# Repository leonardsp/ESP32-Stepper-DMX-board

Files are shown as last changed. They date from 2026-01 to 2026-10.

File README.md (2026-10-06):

# ESP32-Stepper-DMX-board

## DMX Channels

The current firmware implements the real motor + LED-dimmer DMX profile. There is no WLED DMX implementation in this build.

Combined fixture profile (LED dimmer default start address = 8):

1   - LED Pan
2   - LED Pan fine
3   - Ref Pan
4   - Ref Pan fine
5   - LED Pan Inv (0 stop / 1-127 CCW / 128 stop / 129-255 CW)
6   - Ref Pan Inv (0 stop / 1-127 CCW / 128 stop / 129-255 CW)
7   - Reset / Homing (0 no / 1-255 start)
8   - Dimmer 0 coarse
9   - Dimmer 0 fine
10  - Dimmer 1 coarse
11  - Dimmer 1 fine
12  - Dimmer 2 coarse
13  - Dimmer 2 fine
14  - Dimmer 3 coarse
15  - Dimmer 3 fine
16  - Dimmer 4 coarse
17  - Dimmer 4 fine
18  - Dimmer 5 coarse
19  - Dimmer 5 fine
20  - Dimmer 6 coarse
21  - Dimmer 6 fine
22  - Dimmer 7 coarse
23  - Dimmer 7 fine
24  - Strobe (0 off / 1-255 speed)
25-240 - RGB pixel data for 72 LEDs (3 channels per LED)

## Connector Pinout
1 - GND
2 - +24V
3 - DMX_B (xlr pin 2)
4 - DMX_A (xlr pin 3)

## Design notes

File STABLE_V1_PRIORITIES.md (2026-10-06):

# Stable V1 Priorities (ESP32-Stepper-DMX-board)

Stand: 2026-08-28
Ziel: eine technisch stabile, betriebssichere erste Version fuer Show-Einsatz.

## 1) P0 Kritisch (MUSS vor Stable V1)

### P0-3: WS2813/Pixel-Stabilitaet nach DMX-Verlust (nur erste ~10 LEDs / random)
- Symptom: nach DMX-Loss oder sporadisch arbeiten nur erste Pixel korrekt.
- Risiko: sichtbarer Show-Fehler.
- Wahrscheinliche technische Ursachen:
  - Keine harte Paketlaengen-Validierung vor Kanalzugriffen.
  - Treiber ist auf WS2812B konfiguriert, Hardwaremeldung nennt WS2813.
- Entscheidung fuer V1:
  - DMX Paketgroesse strikt validieren (nur verarbeiten, wenn voller Footprint vorhanden).
  - Bei unvollstaendigen Frames: fail-safe (letzter gueltiger Zustand oder definierter Blackout).
  - LED Typ/Timing passend zur realen Hardware fixieren und validieren.

### P0-4: Position + kontinuierliche Rotation verliert Referenz/systematischer Fehler
- Symptom: Positionsdrift/Lost Position bei gleichzeitiger Pan-Position und Rotation.
- Risiko: mechanische Fehlposition im Betrieb.
- Hinweis: wirkt algorithmisch/systematisch, nicht nur Step-Loss.
- Entscheidung fuer V1:
  - Bewegungsmodell vereinheitlichen: klarer Zustandsautomat fuer Position, Hold, Rotation.
  - Offset- und Uebergangslogik (0/128/rotating) deterministisch machen.
  - Reproduzierbarer Testfall als Release-Gate (mehrere Minuten kontinuierlich).

### P0-2: DMX Timeout Anforderung stimmt nicht mit Implementierung
- Anforderung: DMX Timeout = 60s.
- Ist-Code: Timeout steht auf 5s.
- Risiko: unnoetige Motor-Disable/Homing-Zyklen bei kurzen DMX-Aussetzern.
- Entscheidung fuer V1:
  - Timeout auf exakt 60s setzen.
  - Bei Timeout: Stepper disable.
  - Bei DMX Rueckkehr: zwingend Rehoming vor normalem Betrieb.
  - Timeout/Homing Verhalten mit realen DMX-Ausfaellen testen und protokollieren.

### P0-1: COB Fan schaltet nicht sicher bei hoher Last
- Symptom: Luefter startet nicht zuverlaessig, auch wenn COB-Last hoch ist.
- Risiko: thermische Ueberlastung, Leistungsabfall, Hardware-Schaden.
- Beobachtung aus Code:
  - Fan wird ueber einen Integrator mit langer Rise-Time geregelt.
  - Aktivierung erst ueber FAN_ENABLE_THRESHOLD.
- Entscheidung fuer V1:
  - Fan-Sicherheitsmodus einfuehren: bei hoher Last (z. B. >=80% Dimmer oder Pixel-Last >=70%) sofort Fan ON.
  - Thermal-Schutz als harte Prioritaet behandeln (nie ohne aktive Kuehlung bei hoher Last).
  - Kurzer Hardwaretest unter Dauerlast (mind. 20-30 min) als Release-Gate.

### P0-5: Feste DMX-Adressen fuer alle 8 ESP-Controller
- Symptom: uneinheitliche oder nicht final festgelegte DMX-Adressierung im Gesamtsystem.
- Risiko: Patching-Fehler, unvorhersehbares Verhalten im Show-Betrieb, hoher Setup-Aufwand.
- Entscheidung fuer V1:
  - Feste, dokumentierte Startadressen pro Controller definieren.
  - Adressplan in Doku + Konfiguration synchron halten.
  - Endtest mit kompletter 8-ESP-Konstellation als Release-Gate.

## 2) P1 Hoch (sollte in V1 wenn Zeit reicht)

### P1-1: RDM Zuverlaessigkeit im Vollbetrieb
- Symptom: bekannte RDM Probleme.
- Risiko: schlechte Erkennbarkeit/Steuerbarkeit an Lichtpulten.
- Beobachtung:
  - Es gibt separate rdm_test Firmware -> Hinweis auf noch nicht robuste Integration im Hauptbuild.
- Entscheidung fuer V1:
  - RDM Grundfunktionen als Mindestumfang absichern: Discovery, DMX Start Address, Personality, Device Label.
  - Lasttests mit aktivem Pixel/Dimmer-Rendering + RDM Polling.
  - Falls nicht voll stabil: RDM Scope fuer V1 klar begrenzen und dokumentieren.

### P1-2: Fehlerpfad bei Homing-Fehlern
- Symptom: Fehler werden zwar geloggt, aber kaum Recovery/Benutzerfeedback.
- Risiko: unklarer Betriebszustand nach fehlgeschlagenem Homing.
- Entscheidung fuer V1:
  - Klaren Safe-State definieren (Ausgaenge aus, Bewegung stop, Fehlerflag).
  - Sichtbares Fehlerfeedback (z. B. Diagnose-LED oder serieller Fehlercode) definieren.

## 3) P2 Mittel (nach Stable V1 verschiebbar)

### P2-1: Placeholder/TODOs ohne direkten Show-Blocker
- RDM Identify Callback ist nur Platzhalter.
- Geplante Weiterleitung DMX -> Serial2 ist TODO.

### P2-2: Hardware/Validierungsaufgaben aus TODO.md
- Mechanik-/Elektroniktests sind nur teilweise dokumentiert.
- Fuer V1 reicht fokussierter Abnahmetest, umfassende Validierung kann in V1.1 folgen.

## 4) Konkrete Stable-V1 Zieldefinition (MUSS)

1. Pixel-Robustheit: kein "nur erste LEDs" Fehler nach DMX-Loss/Reconnect.
2. Bewegungsstabilitaet: keine systematische Positionsdrift bei Position+Rotation.
3. DMX Fail-Safe: 60s Timeout, dann Stepper disable; bei Rueckkehr obligatorisches Rehoming.
4. Thermische Sicherheit: Fan startet sicher unter hoher Last und verhindert Ueberhitzung.
5. Feste DMX-Adressen fuer die insgesamt 8 verschiedenen ESPs.

## 5) Release Gates (Go/No-Go Tests)

1. 10x DMX Reconnect-Test ohne Pixel-Ausfall/Random-Muster.
2. 20 min Bewegungstest mit gemischter Position/Rotation ohne Referenzverlust.
3. 10x DMX Ausfall/Rueckkehr-Zyklus mit 60s Timeout, jedes Mal korrektes Disable/Rehome.
4. 30 min Vollast-Test (Dimmer + Pixel) ohne thermischen Fehler.
5. RDM Discovery und Parameter-Aenderung von mindestens 2 unterschiedlichen Lichtpult/Tools.

## 6) Empfohlene Reihenfolge (wenn wenig Zeit)

1. Pixel/WS2813 Stabilitaet nach DMX-Loss (P0-3)
2. Rotation+Position Drift fixen (P0-4)
3. DMX Timeout auf 60s + Rehome-Flow absichern (P0-2)
4. Fan/Thermal Fix + Test (P0-1)
5. Feste DMX-Adressen fuer 8 ESPs finalisieren (P0-5)
6. RDM Mindeststabilitaet verifizieren (P1-1)

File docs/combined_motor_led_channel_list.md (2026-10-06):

# Combined DMX Channel List (Motor + LED Dimmer)

This list assumes both controllers run together with LED dimmer default start address at **8**.

| Channel | Name | Controller |
|---:|---|---|
| 1 | LED Pan | motor_dmx |
| 2 | LED Pan fine | motor_dmx |
| 3 | Ref Pan | motor_dmx |
| 4 | Ref Pan fine | motor_dmx |
| 5 | LED Pan Inv (0 stop / 1-127 CCW / 128 stop / 129-255 CW) | motor_dmx |
| 6 | Ref Pan Inv (0 stop / 1-127 CCW / 128 stop / 129-255 CW) | motor_dmx |
| 7 | Reset / Homing (0 no, 1-255 start) | motor_dmx |
| 8 | Dimmer 0 coarse | led_dimmer |
| 9 | Dimmer 0 fine | led_dimmer |
| 10 | Dimmer 1 coarse | led_dimmer |
| 11 | Dimmer 1 fine | led_dimmer |
| 12 | Dimmer 2 coarse | led_dimmer |
| 13 | Dimmer 2 fine | led_dimmer |
| 14 | Dimmer 3 coarse | led_dimmer |
| 15 | Dimmer 3 fine | led_dimmer |
| 16 | Dimmer 4 coarse | led_dimmer |
| 17 | Dimmer 4 fine | led_dimmer |
| 18 | Dimmer 5 coarse | led_dimmer |
| 19 | Dimmer 5 fine | led_dimmer |
| 20 | Dimmer 6 coarse | led_dimmer |
| 21 | Dimmer 6 fine | led_dimmer |
| 22 | Dimmer 7 coarse | led_dimmer |
| 23 | Dimmer 7 fine | led_dimmer |
| 24 | Strobe (0 off, 1-255 speed) | led_dimmer |
| 25 | Pixel 1 Red | led_dimmer |
| 26 | Pixel 1 Green | led_dimmer |
| 27 | Pixel 1 Blue | led_dimmer |
| 28 | Pixel 2 Red | led_dimmer |
| 29 | Pixel 2 Green | led_dimmer |
| 30 | Pixel 2 Blue | led_dimmer |
| 31 | Pixel 3 Red | led_dimmer |
| 32 | Pixel 3 Green | led_dimmer |
| 33 | Pixel 3 Blue | led_dimmer |
| 34 | Pixel 4 Red | led_dimmer |
| 35 | Pixel 4 Green | led_dimmer |
| 36 | Pixel 4 Blue | led_dimmer |
| 37 | Pixel 5 Red | led_dimmer |
| 38 | Pixel 5 Green | led_dimmer |
| 39 | Pixel 5 Blue | led_dimmer |
| 40 | Pixel 6 Red | led_dimmer |
| 41 | Pixel 6 Green | led_dimmer |
| 42 | Pixel 6 Blue | led_dimmer |
| 43 | Pixel 7 Red | led_dimmer |
| 44 | Pixel 7 Green | led_dimmer |
| 45 | Pixel 7 Blue | led_dimmer |
| 46 | Pixel 8 Red | led_dimmer |
| 47 | Pixel 8 Green | led_dimmer |
| 48 | Pixel 8 Blue | led_dimmer |
| 49 | Pixel 9 Red | led_dimmer |
| 50 | Pixel 9 Green | led_dimmer |
| 51 | Pixel 9 Blue | led_dimmer |
| 52 | Pixel 10 Red | led_dimmer |
| 53 | Pixel 10 Green | led_dimmer |
| 54 | Pixel 10 Blue | led_dimmer |
| 55 | Pixel 11 Red | led_dimmer |
| 56 | Pixel 11 Green | led_dimmer |
| 57 | Pixel 11 Blue | led_dimmer |
| 58 | Pixel 12 Red | led_dimmer |
| 59 | Pixel 12 Green | led_dimmer |
| 60 | Pixel 12 Blue | led_dimmer |
| 61 | Pixel 13 Red | led_dimmer |
| 62 | Pixel 13 Green | led_dimmer |
| 63 | Pixel 13 Blue | led_dimmer |
| 64 | Pixel 14 Red | led_dimmer |
| 65 | Pixel 14 Green | led_dimmer |
| 66 | Pixel 14 Blue | led_dimmer |
| 67 | Pixel 15 Red | led_dimmer |
| 68 | Pixel 15 Green | led_dimmer |
| 69 | Pixel 15 Blue | led_dimmer |
| 70 | Pixel 16 Red | led_dimmer |
| 71 | Pixel 16 Green | led_dimmer |
| 72 | Pixel 16 Blue | led_dimmer |
| 73 | Pixel 17 Red | led_dimmer |
| 74 | Pixel 17 Green | led_dimmer |
| 75 | Pixel 17 Blue | led_dimmer |
| 76 | Pixel 18 Red | led_dimmer |
| 77 | Pixel 18 Green | led_dimmer |
| 78 | Pixel 18 Blue | led_dimmer |
| 79 | Pixel 19 Red | led_dimmer |
| 80 | Pixel 19 Green | led_dimmer |
| 81 | Pixel 19 Blue | led_dimmer |
| 82 | Pixel 20 Red | led_dimmer |
| 83 | Pixel 20 Green | led_dimmer |
| 84 | Pixel 20 Blue | led_dimmer |
| 85 | Pixel 21 Red | led_dimmer |
| 86 | Pixel 21 Green | led_dimmer |
| 87 | Pixel 21 Blue | led_dimmer |
| 88 | Pixel 22 Red | led_dimmer |
| 89 | Pixel 22 Green | led_dimmer |
| 90 | Pixel 22 Blue | led_dimmer |
| 91 | Pixel 23 Red | led_dimmer |
| 92 | Pixel 23 Green | led_dimmer |
| 93 | Pixel 23 Blue | led_dimmer |
| 94 | Pixel 24 Red | led_dimmer |
| 95 | Pixel 24 Green | led_dimmer |
| 96 | Pixel 24 Blue | led_dimmer |
| 97 | Pixel 25 Red | led_dimmer |
| 98 | Pixel 25 Green | led_dimmer |
| 99 | Pixel 25 Blue | led_dimmer |
| 100 | Pixel 26 Red | led_dimmer |
| 101 | Pixel 26 Green | led_dimmer |
| 102 | Pixel 26 Blue | led_dimmer |
| 103 | Pixel 27 Red | led_dimmer |
| 104 | Pixel 27 Green | led_dimmer |
| 105 | Pixel 27 Blue | led_dimmer |
| 106 | Pixel 28 Red | led_dimmer |
| 107 | Pixel 28 Green | led_dimmer |
| 108 | Pixel 28 Blue | led_dimmer |
| 109 | Pixel 29 Red | led_dimmer |
| 110 | Pixel 29 Green | led_dimmer |
| 111 | Pixel 29 Blue | led_dimmer |
| 112 | Pixel 30 Red | led_dimmer |
| 113 | Pixel 30 Green | led_dimmer |
| 114 | Pixel 30 Blue | led_dimmer |
| 115 | Pixel 31 Red | led_dimmer |
| 116 | Pixel 31 Green | led_dimmer |
| 117 | Pixel 31 Blue | led_dimmer |
| 118 | Pixel 32 Red | led_dimmer |
| 119 | Pixel 32 Green | led_dimmer |
| 120 | Pixel 32 Blue | led_dimmer |
| 121 | Pixel 33 Red | led_dimmer |
| 122 | Pixel 33 Green | led_dimmer |
| 123 | Pixel 33 Blue | led_dimmer |
| 124 | Pixel 34 Red | led_dimmer |
| 125 | Pixel 34 Green | led_dimmer |
| 126 | Pixel 34 Blue | led_dimmer |
| 127 | Pixel 35 Red | led_dimmer |
| 128 | Pixel 35 Green | led_dimmer |
| 129 | Pixel 35 Blue | led_dimmer |
| 130 | Pixel 36 Red | led_dimmer |
| 131 | Pixel 36 Green | led_dimmer |
| 132 | Pixel 36 Blue | led_dimmer |
| 133 | Pixel 37 Red | led_dimmer |
| 134 | Pixel 37 Green | led_dimmer |
| 135 | Pixel 37 Blue | led_dimmer |
| 136 | Pixel 38 Red | led_dimmer |
| 137 | Pixel 38 Green | led_dimmer |
| 138 | Pixel 38 Blue | led_dimmer |
| 139 | Pixel 39 Red | led_dimmer |
| 140 | Pixel 39 Green | led_dimmer |
| 141 | Pixel 39 Blue | led_dimmer |
| 142 | Pixel 40 Red | led_dimmer |
| 143 | Pixel 40 Green | led_dimmer |
| 144 | Pixel 40 Blue | led_dimmer |
| 145 | Pixel 41 Red | led_dimmer |
| 146 | Pixel 41 Green | led_dimmer |
| 147 | Pixel 41 Blue | led_dimmer |
| 148 | Pixel 42 Red | led_dimmer |
| 149 | Pixel 42 Green | led_dimmer |
| 150 | Pixel 42 Blue | led_dimmer |
| 151 | Pixel 43 Red | led_dimmer |
| 152 | Pixel 43 Green | led_dimmer |
| 153 | Pixel 43 Blue | led_dimmer |
| 154 | Pixel 44 Red | led_dimmer |
| 155 | Pixel 44 Green | led_dimmer |
| 156 | Pixel 44 Blue | led_dimmer |
| 157 | Pixel 45 Red | led_dimmer |
| 158 | Pixel 45 Green | led_dimmer |
| 159 | Pixel 45 Blue | led_dimmer |
| 160 | Pixel 46 Red | led_dimmer |
| 161 | Pixel 46 Green | led_dimmer |
| 162 | Pixel 46 Blue | led_dimmer |
| 163 | Pixel 47 Red | led_dimmer |
| 164 | Pixel 47 Green | led_dimmer |
| 165 | Pixel 47 Blue | led_dimmer |
| 166 | Pixel 48 Red | led_dimmer |
| 167 | Pixel 48 Green | led_dimmer |
| 168 | Pixel 48 Blue | led_dimmer |
| 169 | Pixel 49 Red | led_dimmer |
| 170 | Pixel 49 Green | led_dimmer |
| 171 | Pixel 49 Blue | led_dimmer |
| 172 | Pixel 50 Red | led_dimmer |
| 173 | Pixel 50 Green | led_dimmer |
| 174 | Pixel 50 Blue | led_dimmer |
| 175 | Pixel 51 Red | led_dimmer |
| 176 | Pixel 51 Green | led_dimmer |
| 177 | Pixel 51 Blue | led_dimmer |
| 178 | Pixel 52 Red | led_dimmer |
| 179 | Pixel 52 Green | led_dimmer |
| 180 | Pixel 52 Blue | led_dimmer |
| 181 | Pixel 53 Red | led_dimmer |
| 182 | Pixel 53 Green | led_dimmer |
| 183 | Pixel 53 Blue | led_dimmer |
| 184 | Pixel 54 Red | led_dimmer |
| 185 | Pixel 54 Green | led_dimmer |
| 186 | Pixel 54 Blue | led_dimmer |
| 187 | Pixel 55 Red | led_dimmer |
| 188 | Pixel 55 Green | led_dimmer |
| 189 | Pixel 55 Blue | led_dimmer |
| 190 | Pixel 56 Red | led_dimmer |
| 191 | Pixel 56 Green | led_dimmer |
| 192 | Pixel 56 Blue | led_dimmer |
| 193 | Pixel 57 Red | led_dimmer |
| 194 | Pixel 57 Green | led_dimmer |
| 195 | Pixel 57 Blue | led_dimmer |
| 196 | Pixel 58 Red | led_dimmer |
| 197 | Pixel 58 Green | led_dimmer |
| 198 | Pixel 58 Blue | led_dimmer |
| 199 | Pixel 59 Red | led_dimmer |
| 200 | Pixel 59 Green | led_dimmer |
| 201 | Pixel 59 Blue | led_dimmer |
| 202 | Pixel 60 Red | led_dimmer |
| 203 | Pixel 60 Green | led_dimmer |
| 204 | Pixel 60 Blue | led_dimmer |
| 205 | Pixel 61 Red | led_dimmer |
| 206 | Pixel 61 Green | led_dimmer |
| 207 | Pixel 61 Blue | led_dimmer |
| 208 | Pixel 62 Red | led_dimmer |
| 209 | Pixel 62 Green | led_dimmer |
| 210 | Pixel 62 Blue | led_dimmer |
| 211 | Pixel 63 Red | led_dimmer |
| 212 | Pixel 63 Green | led_dimmer |
| 213 | Pixel 63 Blue | led_dimmer |
| 214 | Pixel 64 Red | led_dimmer |
| 215 | Pixel 64 Green | led_dimmer |
| 216 | Pixel 64 Blue | led_dimmer |
| 217 | Pixel 65 Red | led_dimmer |
| 218 | Pixel 65 Green | led_dimmer |
| 219 | Pixel 65 Blue | led_dimmer |
| 220 | Pixel 66 Red | led_dimmer |
| 221 | Pixel 66 Green | led_dimmer |
| 222 | Pixel 66 Blue | led_dimmer |
| 223 | Pixel 67 Red | led_dimmer |
| 224 | Pixel 67 Green | led_dimmer |
| 225 | Pixel 67 Blue | led_dimmer |
| 226 | Pixel 68 Red | led_dimmer |
| 227 | Pixel 68 Green | led_dimmer |
| 228 | Pixel 68 Blue | led_dimmer |
| 229 | Pixel 69 Red | led_dimmer |
| 230 | Pixel 69 Green | led_dimmer |
| 231 | Pixel 69 Blue | led_dimmer |
| 232 | Pixel 70 Red | led_dimmer |
| 233 | Pixel 70 Green | led_dimmer |
| 234 | Pixel 70 Blue | led_dimmer |
| 235 | Pixel 71 Red | led_dimmer |
| 236 | Pixel 71 Green | led_dimmer |
| 237 | Pixel 71 Blue | led_dimmer |
| 238 | Pixel 72 Red | led_dimmer |
| 239 | Pixel 72 Green | led_dimmer |
| 240 | Pixel 72 Blue | led_dimmer |

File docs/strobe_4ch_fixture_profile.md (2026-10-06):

# Strobe 4CH Fixture Profile

This file documents the DMX personalities and macro channel mapping for the `strobe_4ch` firmware.

## Personalities

### 1) Simple (2ch)
- CH1: Master dimmer (8-bit)
- CH2: Strobe (0=open, 1..255=slow..fast)

### 2) Simple Fine (3ch)
- CH1: Master dimmer coarse
- CH2: Master dimmer fine
- CH3: Strobe

### 3) Simple Macro (3ch)
- CH1: Master dimmer (8-bit)
- CH2: Strobe
- CH3: Macro

### 4) Compatibility (5ch)
- CH1: Dimmer 1 (8-bit)
- CH2: Dimmer 2 (8-bit)
- CH3: Dimmer 3 (8-bit)
- CH4: Dimmer 4 (8-bit)
- CH5: Strobe

### 5) Compatibility Macro (6ch)
- CH1: Dimmer 1 (8-bit)
- CH2: Dimmer 2 (8-bit)
- CH3: Dimmer 3 (8-bit)
- CH4: Dimmer 4 (8-bit)
- CH5: Strobe
- CH6: Macro

### 6) Advanced (10ch)
- CH1: Dimmer 1 coarse
- CH2: Dimmer 1 fine
- CH3: Dimmer 2 coarse
- CH4: Dimmer 2 fine
- CH5: Dimmer 3 coarse
- CH6: Dimmer 3 fine
- CH7: Dimmer 4 coarse
- CH8: Dimmer 4 fine
- CH9: Strobe
- CH10: Macro

## Strobe Channel
- 0 = open (no strobe gating)
- 1..255 = 1..20 Hz mapping

## Macro Channel Mapping (10 speed steps)
- 0 = no macro
- 1..9 = Effect 1 (All On)
- 10..19 = Effect 2, speed 1..10
- 20..29 = Effect 3, speed 1..10
- 30..39 = Effect 4, speed 1..10
- 40..49 = Effect 5, speed 1..10
- 50..59 = Effect 6, speed 1..10
- 60..69 = Effect 7, speed 1..10
- 70..79 = Effect 8, speed 1..10
- 80..89 = Effect 9, speed 1..10
- 90..99 = Effect 10, speed 1..10
- 100..109 = Effect 11, speed 1..10
- 110..119 = Effect 12, speed 1..10
- 120..129 = Effect 13, speed 1..10
- 130..139 = Effect 14, speed 1..10
- 140..149 = Effect 15, speed 1..10
- 150..159 = Effect 16, speed 1..10
- 160..169 = Effect 17, speed 1..10
- 170..179 = Effect 18, speed 1..10
- 180..189 = Effect 19, speed 1..10
- 190..199 = Effect 20, speed 1..10
- 200..209 = Effect 21, speed 1..10
- 210..219 = Effect 22, speed 1..10
- 220..229 = Effect 23, speed 1..10
- 230..239 = Effect 24, speed 1..10
- 240..249 = Effect 25, speed 1..10
- 250..255 = clamped to Effect 25 speed 10

## Macro Effects List
1. All On
2. All Fade
3. Wave 1→4
4. Wave 4→1
5. Single Chase Forward
6. Single Chase Reverse
7. Pair Chase (1+2 / 3+4)
8. Pair Chase (1+4 / 2+3)
9. Bounce Forward
10. Bounce Reverse
11. Theater Chase
12. Random On/Off Mask
13. Random Levels
14. Random Sparkle
15. Random Single Channel
16. Saw Up
17. Saw Down
18. Triangle Fade
19. Breath Halves Opposite
20. Circular Phase Wave
21. Stair Up
22. Stair Down
23. Two-Channel Chase
24. Smooth Random Drift
25. Random Global Flicker

## Notes
- Macros are rendered first, then strobe is applied.
- Thermal/CPU protection can still limit output.
- Advanced personality keeps 16-bit dimmer control path before PWM quantization.

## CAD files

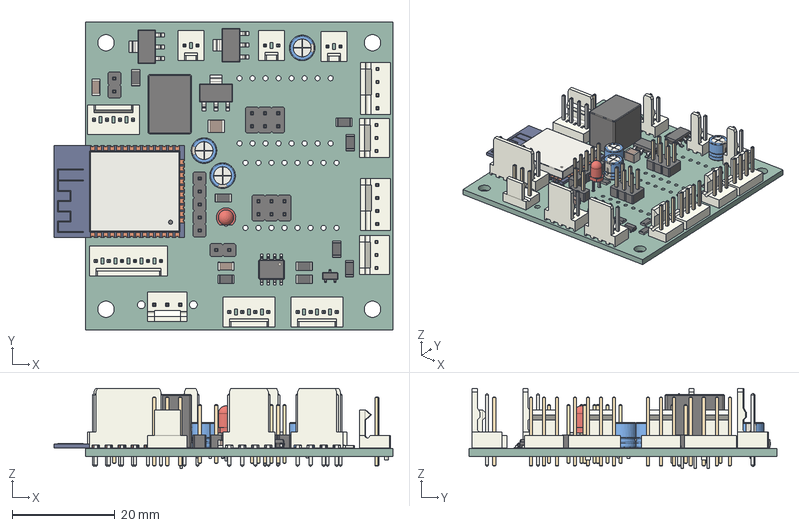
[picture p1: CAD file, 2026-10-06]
Schematics/schematics.step
66.1 x 60.0 x 15.7 mm
R_1206_3216Metric x 9
Molex_KK-254_AE-6410-04A_1x04_P2.54mm_Vertical x 3
Molex_KK-254_AE-6410-06A_1x06_P2.54mm_Vertical
LED_D3.0mm
Converter_DCDC_RECOM_R-78E-0.5_THT
FanPinHeader_1x03_P2.54mm_Vertical x 3
PinHeader_2x03_P2.54mm_Vertical x 2
SOT-223 x 3
ESP32-WROOM-32
Molex_KK-254_AE-6410-02A_1x02_P2.54mm_Vertical x 3
PinHeader_1x02_P2.54mm_Vertical x 2
C_1206_3216Metric x 2
CP_Radial_D5.0mm_P2.00mm x 2
CP_Radial_D5.0mm_P2.50mm
C_1210_3225Metric
FanPinHeader_1x04_P2.54mm_Vertical x 2
PinHeader_1x05_P2.54mm_Vertical
SSOP-8_3.9x5.05mm_P1.27mm
SOT-23
schematics_PCB

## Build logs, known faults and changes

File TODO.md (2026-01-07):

# Hardware
## Mecanics
### 3D Modeling
### Test Rig
Test aufbau erstellen erst kleinen und dann in voller länge. 
## Electronics
Test von Schleifkontakt
Test von Led treibern
Test von hall sensoren
# Software

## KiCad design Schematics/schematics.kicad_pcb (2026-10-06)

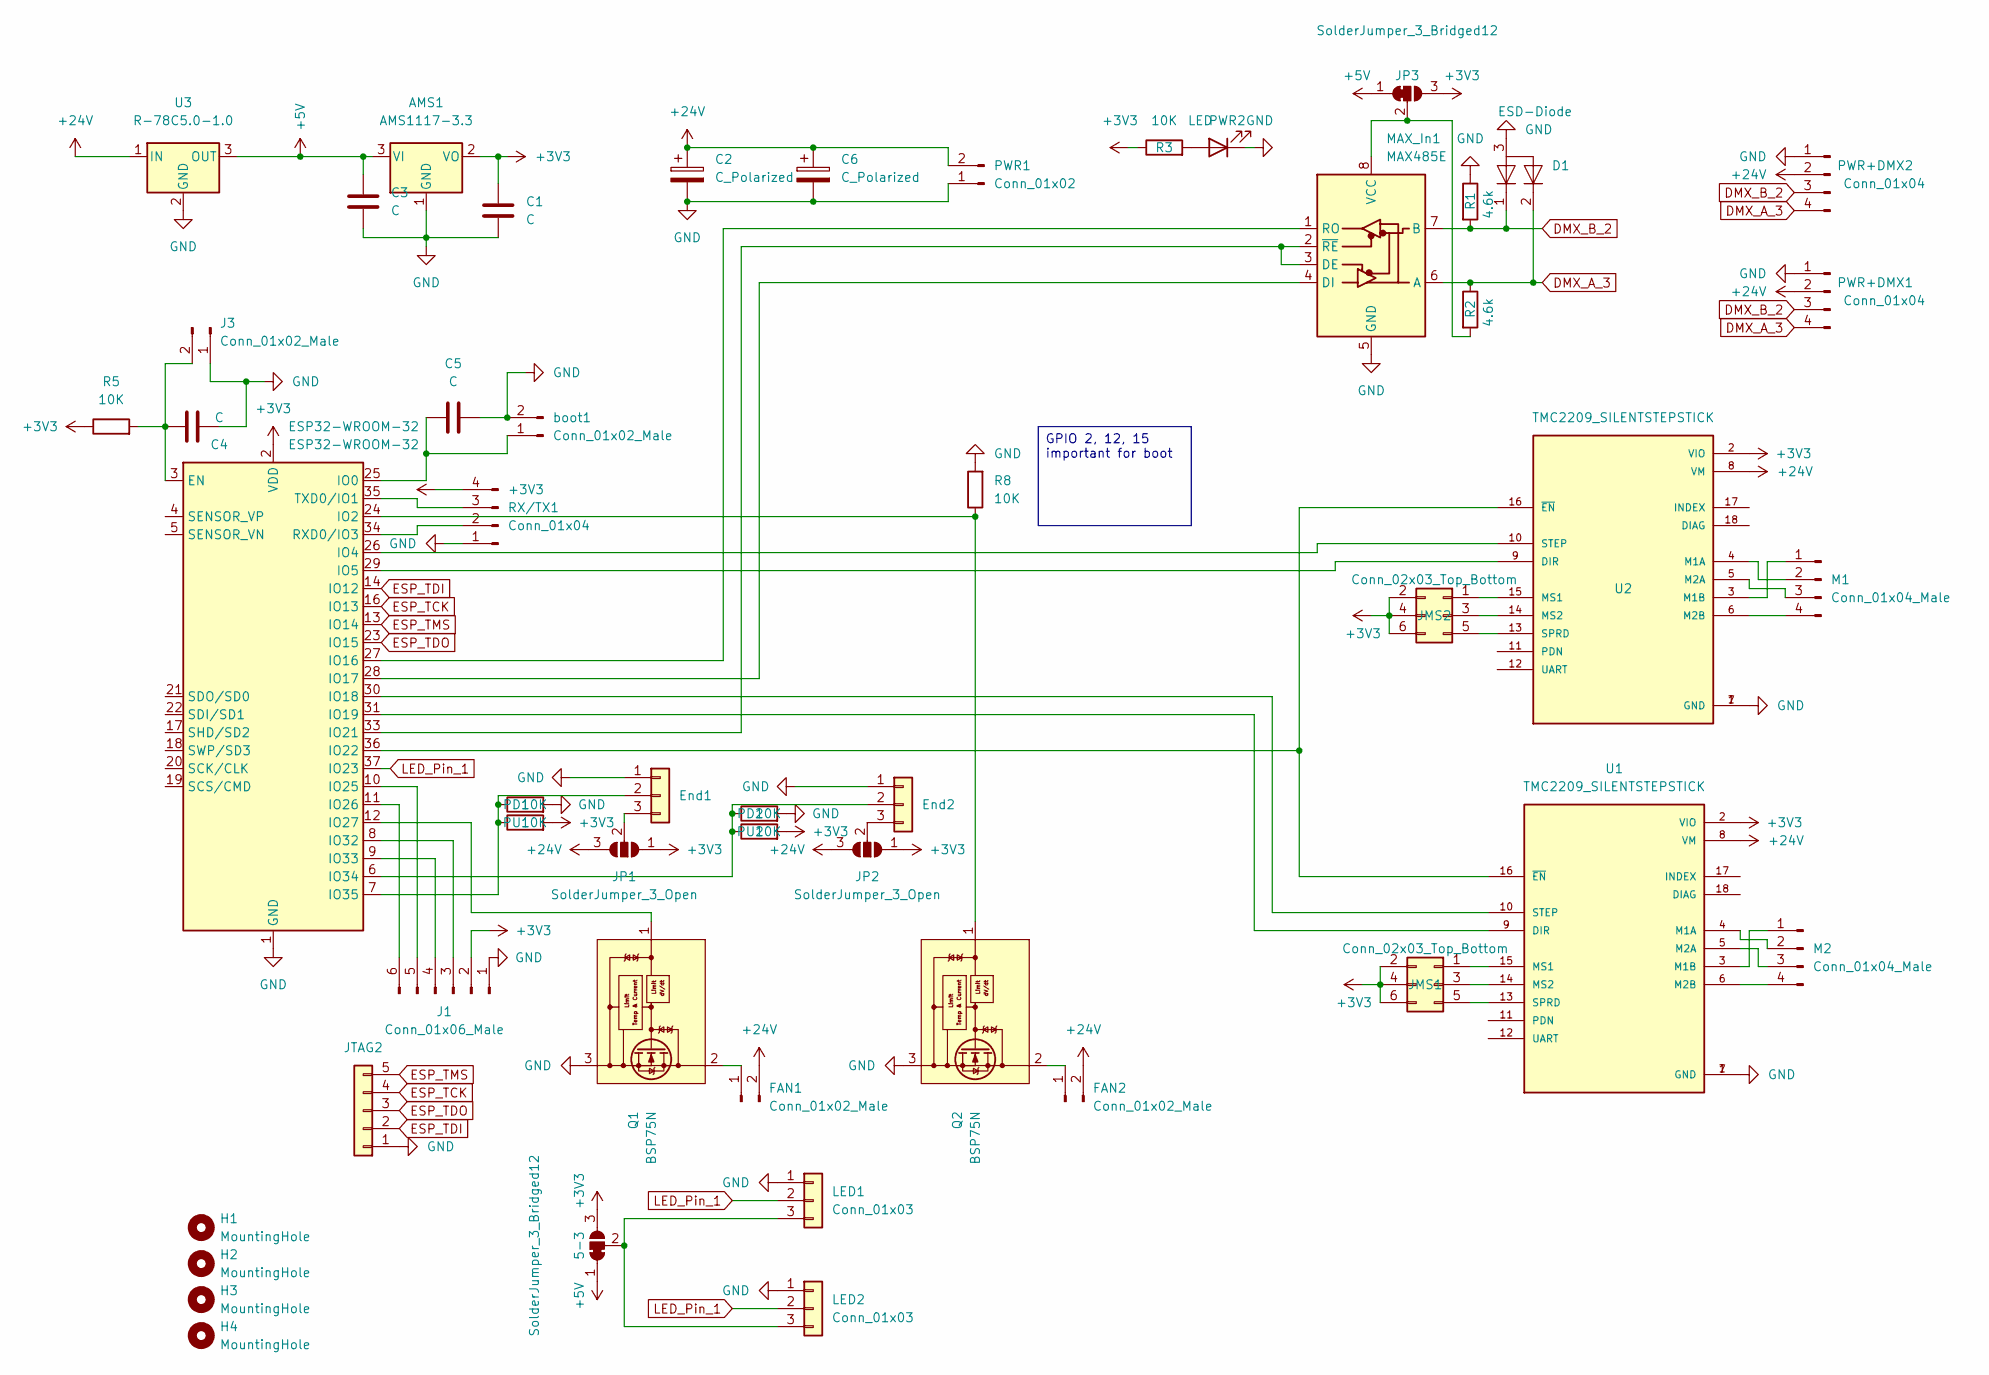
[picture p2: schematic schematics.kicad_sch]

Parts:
5-3: SolderJumper_3_Bridged12; SolderJumper-3_P1.3mm_Bridged12_Pad1.0x1.5mm
AMS1: AMS1117-3.3; SOT-223-3_TabPin2
C1: C; C_1210_3225Metric
C2, C6: C_Polarized; CP_Radial_D5.0mm_P2.00mm
C3: C; CP_Radial_D5.0mm_P2.50mm
C4, C5: C; C_1206_3216Metric
D1: ESD-Diode; SOT-23
ESP32-WROOM-32: ESP32-WROOM-32
End1, End2: Conn_01x03; FanPinHeader_1x03_P2.54mm_Vertical
FAN1, FAN2: Conn_01x02_Male; Molex_KK-254_AE-6410-02A_1x02_P2.54mm_Vertical
H1, H2, H3, H4: MountingHole; MountingHole_3.2mm_M3_DIN965
J1: Conn_01x06_Male; Molex_KK-254_AE-6410-06A_1x06_P2.54mm_Vertical
J2: JTAG2; PinHeader_1x05_P2.54mm_Vertical
J3: Conn_01x02_Male; PinHeader_1x02_P2.54mm_Vertical
JMS1, JMS2: Conn_02x03_Top_Bottom; PinHeader_2x03_P2.54mm_Vertical
JP1, JP2: SolderJumper_3_Open; SolderJumper-3_P1.3mm_Open_Pad1.0x1.5mm
JP3: SolderJumper_3_Bridged12; SolderJumper-3_P1.3mm_Bridged12_Pad1.0x1.5mm
LED1: Conn_01x03; FanPinHeader_1x03_P2.54mm_Vertical
LED2: Conn_01x03; TerminalBlock_bornier-3_P5.08mm
M1, M2: Conn_01x04_Male; FanPinHeader_1x04_P2.54mm_Vertical
MAX_In1: MAX485E; SSOP-8_3.9x5.05mm_P1.27mm
PD1, PD2: 10K; R_1206_3216Metric
PU1, PU2: 10K; R_1206_3216Metric
PWR1: Conn_01x02; Molex_KK-254_AE-6410-02A_1x02_P2.54mm_Vertical
PWR2: LED; LED_D3.0mm
PWR+DMX1, PWR+DMX2: Conn_01x04; Molex_KK-254_AE-6410-04A_1x04_P2.54mm_Vertical
Q1, Q2: BSP75N; SOT-223
R1, R2: 4.6k; R_1206_3216Metric
R3, R5, R8: 10K; R_1206_3216Metric
RX/TX1: Conn_01x04; Molex_KK-254_AE-6410-04A_1x04_P2.54mm_Vertical
U1, U2: TMC2209_SILENTSTEPSTICK; MODULE_TMC2209_SILENTSTEPSTICK
U3: R-78C5.0-1.0; Converter_DCDC_RECOM_R-78E-0.5_THT
boot1: Conn_01x02_Male; PinHeader_1x02_P2.54mm_Vertical

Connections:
+3V3: 5-3.3 (B), AMS1.2 (VO), C1.2, ESP32-WROOM-32.2 (VDD), J1.2, JMS1.2, JMS1.4, JMS1.6, JMS2.2, JMS2.4, JMS2.6, JP1.1 (A), JP2.1 (A), JP3.3 (B), PU1.2, PU2.2, R3.1, R5.1, RX/TX1.4, U1.2 (VIO), U2.2 (VIO)
+5V: 5-3.1 (A), AMS1.3 (VI), C3.1, JP3.1 (A), U3.3 (OUT)
+24V: C2.1, C6.1, FAN1.2, FAN2.2, JP1.3 (B), JP2.3 (B), PWR1.2, PWR+DMX1.2, PWR+DMX2.2, U1.8 (VM), U2.8 (VM), U3.1 (IN)
DMX_A_3: D1.2, MAX_In1.6 (A), PWR+DMX1.4, PWR+DMX2.4, R2.1
DMX_B_2: D1.1, MAX_In1.7 (B), PWR+DMX1.3, PWR+DMX2.3, R1.2
ESP_TCK: ESP32-WROOM-32.16 (IO13), J2.4
ESP_TDI: ESP32-WROOM-32.14 (IO12), J2.2
ESP_TDO: ESP32-WROOM-32.23 (IO15), J2.3
ESP_TMS: ESP32-WROOM-32.13 (IO14), J2.5
GND: AMS1.1 (GND), C1.1, C2.2, C3.2, C4.2, C5.2, C6.2, D1.3, ESP32-WROOM-32.1 (GND), ESP32-WROOM-32.15 (GND), ESP32-WROOM-32.38 (GND), ESP32-WROOM-32.39 (GND), End1.1, End2.1, J1.1, J2.1, J3.1, LED1.1, LED2.1, MAX_In1.5 (GND), PD1.2, PD2.2, PWR1.1, PWR2.1 (K), PWR+DMX1.1, PWR+DMX2.1, Q1.3 (S), Q1.4 (S), Q2.3 (S), Q2.4 (S), R1.1, R8.2, RX/TX1.1, U1.1 (GND), U1.7 (GND), U2.1 (GND), U2.7 (GND), U3.2 (GND), boot1.2
LED_Pin_1: ESP32-WROOM-32.37 (IO23), LED1.2, LED2.2
unnamed: 5-3.2 (C), LED1.3, LED2.3
unnamed: C4.1, ESP32-WROOM-32.3 (EN), J3.2, R5.2
unnamed: C5.1, ESP32-WROOM-32.25 (IO0), boot1.1
unnamed: ESP32-WROOM-32.6 (IO34), End2.2, PD2.1, PU2.1
unnamed: ESP32-WROOM-32.7 (IO35), End1.2, PD1.1, PU1.1
unnamed: ESP32-WROOM-32.8 (IO32), J1.3
unnamed: ESP32-WROOM-32.9 (IO33), J1.4
unnamed: ESP32-WROOM-32.10 (IO25), J1.5
unnamed: ESP32-WROOM-32.11 (IO26), J1.6
unnamed: ESP32-WROOM-32.12 (IO27), Q1.1 (G)
unnamed: ESP32-WROOM-32.24 (IO2), Q2.1 (G), R8.1
unnamed: ESP32-WROOM-32.26 (IO4), U2.10 (STEP)
unnamed: ESP32-WROOM-32.27 (IO16), MAX_In1.1 (RO)
unnamed: ESP32-WROOM-32.28 (IO17), MAX_In1.4 (DI)
unnamed: ESP32-WROOM-32.29 (IO5), U2.9 (DIR)
unnamed: ESP32-WROOM-32.30 (IO18), U1.10 (STEP)
unnamed: ESP32-WROOM-32.31 (IO19), U1.9 (DIR)
unnamed: ESP32-WROOM-32.33 (IO21), MAX_In1.2 (~RE), MAX_In1.3 (DE)
unnamed: ESP32-WROOM-32.34 (RXD0/IO3), RX/TX1.2
unnamed: ESP32-WROOM-32.35 (TXD0/IO1), RX/TX1.3
unnamed: ESP32-WROOM-32.36 (IO22), U1.16 (~EN), U2.16 (~EN)
unnamed: End1.3, JP1.2 (C)
unnamed: End2.3, JP2.2 (C)
unnamed: FAN1.1, Q1.2 (D)
unnamed: FAN2.1, Q2.2 (D)
unnamed: JMS1.1, U1.15 (MS1)
unnamed: JMS1.3, U1.14 (MS2)
unnamed: JMS1.5, U1.13 (SPRD)
unnamed: JMS2.1, U2.15 (MS1)
unnamed: JMS2.3, U2.14 (MS2)
unnamed: JMS2.5, U2.13 (SPRD)
unnamed: JP3.2 (C), MAX_In1.8 (VCC), R2.2
unnamed: M1.1, U2.3 (M1B)
unnamed: M1.2, U2.4 (M1A)
unnamed: M1.3, U2.5 (M2A)
unnamed: M1.4, U2.6 (M2B)
unnamed: M2.1, U1.3 (M1B)
unnamed: M2.2, U1.4 (M1A)
unnamed: M2.3, U1.5 (M2A)
unnamed: M2.4, U1.6 (M2B)
unnamed: PWR2.2 (A), R3.2

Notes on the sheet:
GPIO 2, 12, 15 important for boot

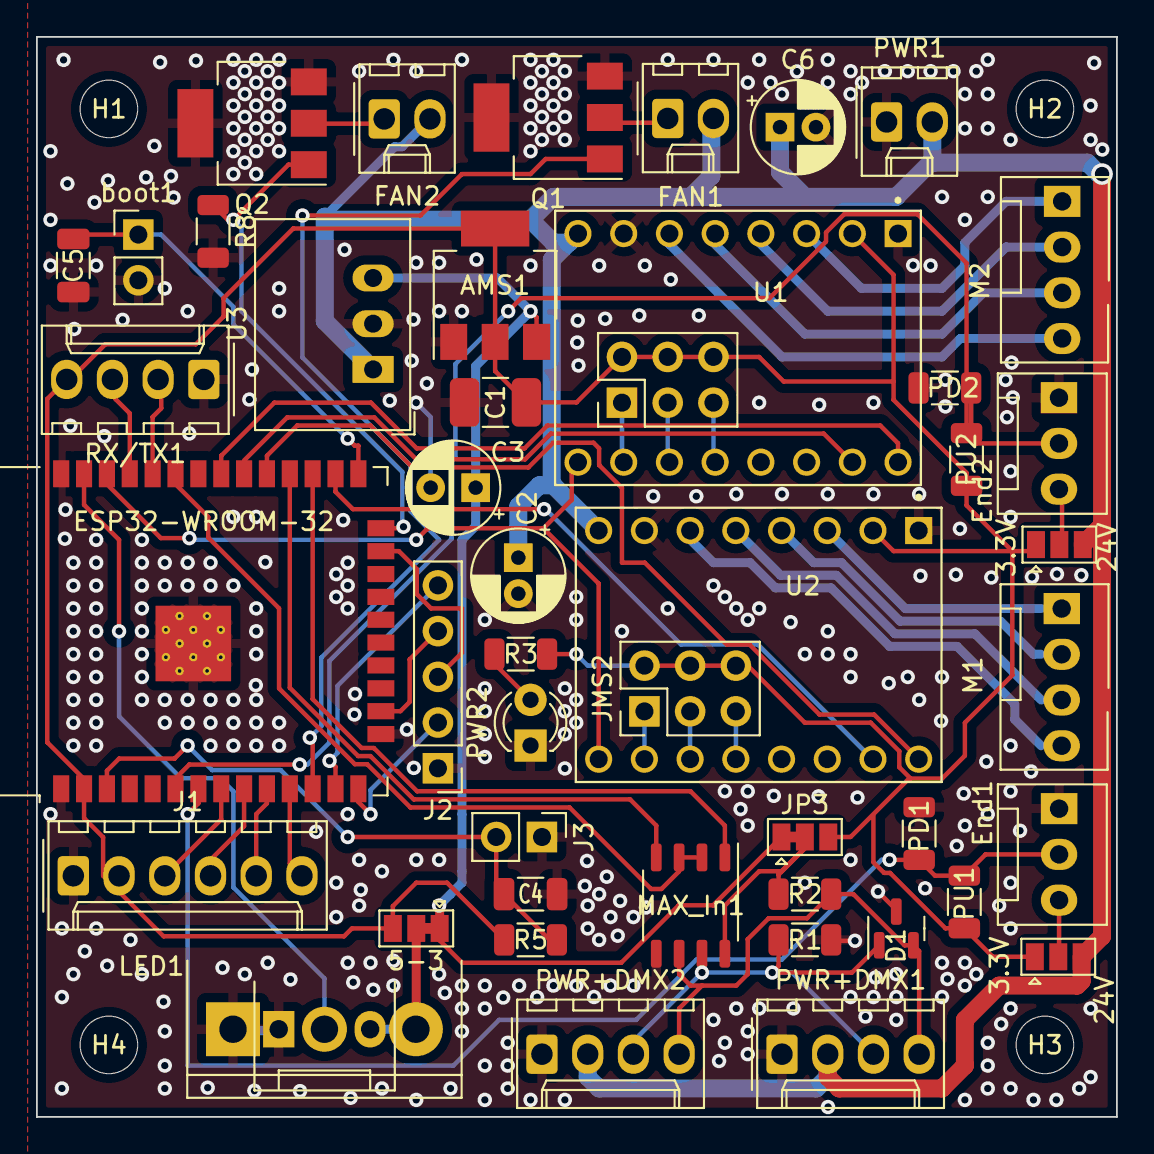
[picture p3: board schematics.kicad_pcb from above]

Board: 2 copper layers, 60.0 x 60.0 mm, 51 parts (0 on the bottom side), 52 nets.

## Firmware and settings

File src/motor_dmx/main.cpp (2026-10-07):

#include <Arduino.h>
#include "pinConfig.h"
#include "FastAccelStepper.h"
#include <cstring>
#include <math.h>
#include <esp_dmx.h>
#include <rdm/responder.h>
#include <rdm/responder/include/product_info.h>
#include <WiFi.h>
#include <WebServer.h>
#include <DNSServer.h>
#include <Preferences.h>

#define Microstepping 32
#define Acceleration 1500*Microstepping
#define MaxSpeed 300*Microstepping //500*Microstepping im ersten Prototyp

// Diagnostic mode: bypass DMX/homing entirely and just oscillate the Ref axis.
// Enable temporarily to verify Ref motor movement in isolation (scope/observe GPIO18/19).
#define TEST_REF_MOTOR_ONLY 0

/*********ChannelList*******
Absolute channels (start address 241):
1/242 - LED Pan
2/243 - LED Pan fine
3/244 - Ref Pan
4/245 - Ref Pan fine
5/246 - LED Pan Inv (0 Stop / 1-127 ccw / 128 Stop /129-255 cw)
6/247 - Ref Pan Inv (0 Stop / 1-127 ccw / 128 Stop /129-255 cw)
7/248 - Reset (0 No 1-255 Start Homing)
8-241/249-481 led_dimmer main.cpp for LED and Dimmer channels
***************************/
uint16_t dmxStartAdresse  = 1; // Default DMX start address 1 or 241 to fit 2 in one universe

const int GerarRatio_LED = 3; // 20 teeth / 60 teeth
const int GerarRatio_Ref = 4; // 20 teeth / 80 teeth
const unsigned int MaxSpeedLED = MaxSpeed*GerarRatio_LED;
const unsigned int MaxSpeedRef = MaxSpeed*GerarRatio_Ref;
const int AccelerationLED = Acceleration*GerarRatio_LED;  // FastAccelStepper nutzt Hz/s
const int AccelerationRef = Acceleration*GerarRatio_Ref;  // FastAccelStepper nutzt Hz/s


// Offsets in output-axis microsteps; defaults until saved via the config page
int Offset_LED = (45-50)*GerarRatio_LED*Microstepping; //lamp 1: 46, lamp 2 has +90° offset
const int MaxPos_LED = 200*Microstepping*GerarRatio_LED*2; //steps per rev*Microstepping*Gear reatior* 2 rounds
const int HomePos_LED = MaxPos_LED/2;

int Offset_Ref = 25*GerarRatio_Ref*Microstepping; //lamp 1: 16, lamp 2 has +90° offset
bool flipLED = false; // Inverts the motor direction pin, as if the motor was wired the other way round
bool flipRef = false;
int savedOffset_LED = 0; // Last persisted values, for the config page reset button
int savedOffset_Ref = 0;
const int MaxPos_Ref = 200*Microstepping*GerarRatio_Ref*2; //steps per rev*Microstepping*Gear reatior* 2 rounds
const int HomePos_Ref = MaxPos_Ref/2;

// Create FastAccelStepper Engine and Stepper Objects
FastAccelStepperEngine engine = FastAccelStepperEngine();
FastAccelStepper *stepperLED = NULL;
FastAccelStepper *stepperRef = NULL;

// DMX receiver using esp_dmx (DMX only, no RDM)
int transmitPin = 17;
int receivePin = 16;
int enablePin = Max485_TR;
byte  dmxValues[DMX_PACKET_SIZE] = {0}; // Initialize to zeros
volatile uint16_t PanValues[2] = {0, 0}; // Initialize to zeros

dmx_port_t dmxPort = 1;

unsigned long lastDMXTime = 0;
volatile bool dmxReceived = false; // Set once a valid DMX frame has arrived
bool enable = true;

// DMX timeout and idle mode
const unsigned long DMX_TIMEOUT_MS = 20 * 1000; // 60 seconds in milliseconds
volatile bool motorsIdle = false; // True when motors are disabled due to DMX timeout
volatile bool needsRehoming = false; // True when DMX returns after timeout

// Startup flag to prevent position task from interfering with homing
volatile bool setupComplete = false;
volatile bool isHoming = false; // Flag set during homing to pause position task
volatile bool wifiActive = false; // Config access point is up; motors hold position

// RDM device hours tracking
unsigned long deviceStartMillis = 0;
unsigned long lastDeviceHoursUpdate = 0;

// Temperature tracking
float temperatureMin = 999.0;  // Initialize to impossible high value
float temperatureMax = -999.0; // Initialize to impossible low value
bool temperatureInitialized = false;
bool homingSingleAxis(FastAccelStepper* stepper, byte hallSensorPin, int maxDis, int offset, unsigned int axisMaxSpeed, int axisAcceleration) {
  // Home eine einzelne Achse mit einem Hall-Sensor
  const char* axisName = (hallSensorPin == Switch_1) ? "LED" : "Ref";
  
  Serial.print("Homing ");
  Serial.print(axisName);
  Serial.print(" - Initial sensor state: ");
  Serial.println(digitalRead(hallSensorPin));
  
  // Setze Homing-Speed und Acceleration (langsamer für Zuverlässigkeit)
  stepper->setSpeedInHz(axisMaxSpeed/4);  // War /2, jetzt /4
  stepper->setAcceleration(axisAcceleration/4);  // War /2, jetzt /4
  
  // Wenn Hall-Sensor bereits getriggert ist, bewege zuerst weg
  if (!digitalRead(hallSensorPin)) { // Sensor ist LOW (getriggert)
    Serial.println("  Sensor already triggered, moving away...");
    stepper->move(maxDis/16); // Bewege 1/16 der maximalen Distanz vorwärts
    while(stepper->isRunning()) { delay(1); }
    delay(100); // Kurze Pause
    Serial.print("  After move away, sensor: ");
    Serial.println(digitalRead(hallSensorPin));
  }
  
  // Bewege in negative Richtung bis Hall-Sensor getriggert wird
  Serial.println("  Searching for sensor...");
  stepper->move(-maxDis/2);
  delay(200);  // Längere Wartezeit damit Bewegung sicher gestartet ist
  
  // Verify stepper is actually moving
  if (!stepper->isRunning()) {
    Serial.println("  WARNING: Stepper not running after move command!");
    delay(100);
  }
  
  Serial.print("  Motor running: ");
  Serial.print(stepper->isRunning());
  Serial.print(", Target: ");
  Serial.println(stepper->targetPos());
  
  // Warte bis Hall-Sensor getriggert wird oder Bewegung stoppt
  unsigned long searchStart = millis();
  while(digitalRead(hallSensorPin)) { // Warte bis LOW (Sensor getriggert)
    if(!stepper->isRunning()) {
      Serial.print("  ERROR: Sensor not found! Time: ");
      Serial.print(millis() - searchStart);
      Serial.print("ms, Final pos: ");
      Serial.print(stepper->getCurrentPosition());
      Serial.print(", Sensor: ");
      Serial.println(digitalRead(hallSensorPin));
      stepper->setSpeedInHz(axisMaxSpeed);
      stepper->setAcceleration(axisAcceleration);
      return false;
    }
    delay(1);
  }
  
  Serial.println("  Sensor found!");
  
  // Sensor gefunden, stoppe und setze temporäre Position
  stepper->forceStopAndNewPosition(0);
  delay(10);
  
  // Bewege etwas weg vom Sensor
  stepper->moveTo(200);
  while(stepper->isRunning()) { delay(1); }
  
  // Langsam zurück für präzise Position (1/15 Geschwindigkeit - guter Kompromiss)
  stepper->setSpeedInHz(axisMaxSpeed/15);
  stepper->setAcceleration(axisAcceleration/15);
  stepper->move(-400);
  
  // Warte bis Sensor wieder getriggert wird
  while(digitalRead(hallSensorPin)) { // Warte bis LOW
    if (!stepper->isRunning()) {
      stepper->move(-1);
    }
    delay(1);
  }
  
  // Präzise Position gefunden:
  // 1) physisch zu Offset fahren
  // 2) logische Position auf Center setzen
  stepper->forceStopAndNewPosition(0);
  stepper->setSpeedInHz(axisMaxSpeed);
  stepper->setAcceleration(axisAcceleration);
  stepper->moveTo(offset);
  while(stepper->isRunning()) { delay(1); }
  int centerPos = maxDis / 2;
  stepper->setCurrentPosition(centerPos);
  
  Serial.print("  ");
  Serial.print(axisName);
  Serial.println(" homing complete");
  delay(10);
  return true;
}

bool homeBothAxes() {
  // Komplette Homing-Sequenz für beide Achsen mit separaten Hall-Sensoren
  // Gibt true zurück wenn erfolgreich, false bei Fehler
  Serial.println("Homing...");
  isHoming = true;
  
  // Home LED-Achse mit Switch_1
  if (!homingSingleAxis(stepperLED, Switch_1, MaxPos_LED, Offset_LED, MaxSpeedLED, AccelerationLED)) {
    isHoming = false;
    return false; // LED-Achse Homing fehlgeschlagen
  }
  
  // Home Ref-Achse mit Switch_2
  if (!homingSingleAxis(stepperRef, Switch_2, MaxPos_Ref, Offset_Ref, MaxSpeedRef, AccelerationRef)) {
    isHoming = false;
    return false; // Ref-Achse Homing fehlgeschlagen
  }
  
  Serial.println("Homing complete\n");
  isHoming = false;
  return true; // Homing erfolgreich
}

void testHomingAccuracy(int iterations = 5) {
  Serial.print("\nTesting homing accuracy (");
  Serial.print(iterations);
  Serial.println(" cycles)...\n");
  
  long ledPositions[10];
  long refPositions[10];
  
  // Test LED axis
  for (int i = 0; i < iterations && i < 10; i++) {
    // Move away from sensor first
    if (i > 0) {
      stepperLED->move(5000);
      while(stepperLED->isRunning()) { delay(1); }
      delay(100);
    }
    
    // Slow approach to sensor (1/15 speed - same as homing)
    stepperLED->setSpeedInHz(MaxSpeedLED/15);
    stepperLED->setAcceleration(AccelerationLED/15);
    stepperLED->move(-MaxPos_LED);
    delay(50);
    
    // Wait for sensor trigger
    while(digitalRead(Switch_1)) {
      if(!stepperLED->isRunning()) {
        Serial.println("ERROR: LED sensor not found!");
        return;
      }
      delay(1);
    }
    
    // Record position at trigger (trigger edge approach)
    stepperLED->forceStop();
    delay(10);
    ledPositions[i] = stepperLED->getCurrentPosition();
    
    // Reset speed
    stepperLED->setSpeedInHz(MaxSpeedLED);
    stepperLED->setAcceleration(AccelerationLED);
  }
  
  // Calculate LED statistics
  long ledMin = ledPositions[0];
  long ledMax = ledPositions[0];
  long ledSum = 0;
  for (int i = 0; i < iterations; i++) {
    ledSum += ledPositions[i];
    if (ledPositions[i] < ledMin) ledMin = ledPositions[i];
    if (ledPositions[i] > ledMax) ledMax = ledPositions[i];
  }
  long ledAvg = ledSum / iterations;
  long ledRange = ledMax - ledMin;
  
  // Calculate degrees (steps per rev = 200 * Microstepping * GerarRatio_LED)
  float stepsPerRevLED = 200.0 * Microstepping * GerarRatio_LED;
  float ledRangeDegrees = (ledRange / stepsPerRevLED) * 360.0;
  
  Serial.println("LED Axis:");
  Serial.print("  Range: ");
  Serial.print(ledRange);
  Serial.print(" microsteps = ");
  Serial.print((float)ledRange / Microstepping, 2);
  Serial.print(" full steps = ");
  Serial.print(ledRangeDegrees, 4);
  Serial.println(" degrees");
  
  // Test Ref axis
  for (int i = 0; i < iterations && i < 10; i++) {
    // Move away from sensor first
    if (i > 0) {
      stepperRef->move(5000);
      while(stepperRef->isRunning()) { delay(1); }
      delay(100);
    }
    
    // Slow approach to sensor (1/15 speed - same as homing)
    stepperRef->setSpeedInHz(MaxSpeedRef/15);
    stepperRef->setAcceleration(AccelerationRef/15);
    stepperRef->move(-MaxPos_Ref);
    delay(50);
    
    // Wait for sensor trigger
    while(digitalRead(Switch_2)) {
      if(!stepperRef->isRunning()) {
        Serial.println("ERROR: Ref sensor not found!");
        return;
      }
      delay(1);
    }
    
    // Record position at trigger (trigger edge approach)
    stepperRef->forceStop();
    delay(10);
    refPositions[i] = stepperRef->getCurrentPosition();
    
    // Reset speed
    stepperRef->setSpeedInHz(MaxSpeedRef);
    stepperRef->setAcceleration(AccelerationRef);
  }
  
  // Calculate Ref statistics
  long refMin = refPositions[0];
  long refMax = refPositions[0];
  long refSum = 0;
  for (int i = 0; i < iterations; i++) {
    refSum += refPositions[i];
    if (refPositions[i] < refMin) refMin = refPositions[i];
    if (refPositions[i] > refMax) refMax = refPositions[i];
  }
  long refAvg = refSum / iterations;
  long refRange = refMax - refMin;
  
  // Calculate degrees (steps per rev = 200 * Microstepping * GerarRatio_Ref)
  float stepsPerRevRef = 200.0 * Microstepping * GerarRatio_Ref;
  float refRangeDegrees = (refRange / stepsPerRevRef) * 360.0;
  
  Serial.println("Ref Axis:");
  Serial.print("  Range: ");
  Serial.print(refRange);
  Serial.print(" microsteps = ");
  Serial.print((float)refRange / Microstepping, 2);
  Serial.print(" full steps = ");
  Serial.print(refRangeDegrees, 4);
  Serial.println(" degrees\n");
}

TaskHandle_t dmxTask;
TaskHandle_t positionTask;

byte fanValue = 0;
long targetPos[2] = {0, 0}; // Initialize to zeros
double rotationOffset[2] = {0.0, 0.0}; // Accumulated position from rotation (double to avoid per-loop truncation drift)
byte rotationSpeed[2] = {0, 0}; // Initialize to stopped (0 = stop)
unsigned long lastPositionUpdateTime = 0;

// DMX frame interpolation for smooth low-speed movement
volatile long previousPanValues[2] = {0, 0};
volatile long currentPanValues[2] = {0, 0};
volatile unsigned long lastDMXReceiveTime = 0;
const unsigned long DMX_FRAME_INTERVAL = 23; // ~44Hz DMX refresh rate
volatile unsigned long dmxInterpolationInterval = DMX_FRAME_INTERVAL;
portMUX_TYPE motionDataMux = portMUX_INITIALIZER_UNLOCKED; // Protects access to motion data (previous/current pan values, rotation speed, last DMX receive time, interpolation interval)

double smoothedCommandPos[2] = {0.0, 0.0};
double smoothedCommandVel[2] = {0.0, 0.0};
bool smoothingInitialized = false;

const float POSITION_TRACK_KP = 18.0f;  // Higher gain to recover long-move responsiveness
const float COMMAND_ACCEL_FACTOR = 4.0f; // Command trajectory accel > motor accel to avoid double filtering
const float HOLD_VELOCITY_EPS = 5.0f;   // Steps/s threshold for considering axis settled
const float HOLD_POSITION_EPS = 1.0f;   // Steps threshold for snap-to-target at rest

inline bool isRotationHoldValue(byte speed) {
  return speed == 128;
}

void updateAxisTracking(FastAccelStepper* stepper, int axisIndex, long desiredPos, uint32_t axisMaxSpeed, int32_t axisAcceleration, float dtSeconds) {
  float positionError = (float)desiredPos - (float)smoothedCommandPos[axisIndex];
  float desiredVelocity = positionError * POSITION_TRACK_KP;
  desiredVelocity = constrain(desiredVelocity, -(float)axisMaxSpeed, (float)axisMaxSpeed);

  float velocityError = desiredVelocity - (float)smoothedCommandVel[axisIndex];
  float maxVelocityDelta = (float)axisAcceleration * COMMAND_ACCEL_FACTOR * dtSeconds;
  velocityError = constrain(velocityError, -maxVelocityDelta, maxVelocityDelta);
  smoothedCommandVel[axisIndex] += velocityError;
  smoothedCommandPos[axisIndex] += smoothedCommandVel[axisIndex] * dtSeconds;

  if (fabsf(positionError) < HOLD_POSITION_EPS && fabsf((float)smoothedCommandVel[axisIndex]) < HOLD_VELOCITY_EPS) {
    smoothedCommandPos[axisIndex] = (double)desiredPos;
    smoothedCommandVel[axisIndex] = 0.0;
  }

  long smoothedTarget = (long)roundf((float)smoothedCommandPos[axisIndex]);
  if (targetPos[axisIndex] != smoothedTarget) {
    stepper->moveTo(smoothedTarget);
    targetPos[axisIndex] = smoothedTarget;
  }
}
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
void loop() {
  // FastAccelStepper runs automatically in background via hardware timers
  // No need to call run() anymore!
  
  static unsigned long lastTempPrint = 0;
  static unsigned long lastTimeoutCheck = 0;
  unsigned long now = millis();
  
  if (wifiActive) {
    webServer.handleClient();
    dnsServer.processNextRequest();
    if (dmxReceived) {
      stopConfigWifi("DMX received");
    } else {
      if (WiFi.softAPgetStationNum() > 0) wifiLastActivityMs = now;
      if (now - wifiLastActivityMs >= WIFI_IDLE_TIMEOUT_MS) stopConfigWifi("idle timeout");
    }
  }

  // Check for DMX timeout every second
  if (now - lastTimeoutCheck >= 1000) {
    lastTimeoutCheck = now;
    unsigned long timeSinceLastDMX = now - lastDMXTime;
    
    // If DMX timeout occurred and motors are not yet idle, disable them
    if (!wifiActive && !motorsIdle && timeSinceLastDMX >= DMX_TIMEOUT_MS) {
      Serial.println("DMX timeout - disabling motors and entering idle mode");
      motorsIdle = true;
      stepperLED->disableOutputs();
      stepperRef->disableOutputs();
      Serial.printf("No DMX signal for %lu seconds\n", timeSinceLastDMX / 1000);
    }
  }
  
  // Print CPU temperature every 10 seconds
  if (now - lastTempPrint >= 10000) {
    float temp = temperatureRead();
    Serial.printf("CPU Temperature: %.1f°C", temp);
    
    // Track min/max
    if (!temperatureInitialized) {
      temperatureMin = temp;
      temperatureMax = temp;
      temperatureInitialized = true;
    } else {
      if (temp < temperatureMin) temperatureMin = temp;
      if (temp > temperatureMax) temperatureMax = temp;
    }
    
    if (temperatureInitialized) {
      Serial.printf(" (Low: %.1f°C, High: %.1f°C)", temperatureMin, temperatureMax);
    }
    Serial.println();
    lastTempPrint = now;
  }
  
  delay(10);
}

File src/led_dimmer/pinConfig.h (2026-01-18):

#define Fan_1       27
#define Fan_2       2
#define Switch_1    35 // not used in led dimmer 
#define Switch_2    34 // not used in led dimmer

#define DimmerPin4  18
#define DimmerPin5  19

#define DimmerPin6   4
#define DimmerPin7   5

#define StepperEnable       22 // not used in led dimmer

#define DimmerPin0  32
#define DimmerPin1  33
#define DimmerPin2  25
#define DimmerPin3  26
#define LEDPin      23

//Max485 on Serial1
#define Max485_TR   21

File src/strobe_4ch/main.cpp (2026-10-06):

#include <Arduino.h>
#include <WiFi.h>
#include <esp_dmx.h>
#include <rdm/responder.h>
#include <rdm/responder/include/power_lamp.h>
#include <rdm/responder/include/utils.h>
#include <dmx/include/parameter.h>
#include <dmx/include/service.h>
#include <dmx/hal/include/nvs.h>
#include "pinConfig.h"

#define DMX_START_ADDRESS 1

constexpr dmx_port_t DMX_PORT = 1;
constexpr int TRANSMIT_PIN = 17;
constexpr int RECEIVE_PIN = 16;
constexpr int ENABLE_PIN = Max485_TR;

constexpr int DIMMER_COUNT = 4;
constexpr int PWM_FREQUENCY = 2000;
constexpr int PWM_RESOLUTION = 12;
constexpr float PWM_OUTPUT_LIMIT = 0.80f;
constexpr int PERSONALITY_COUNT = 3;
constexpr rdm_pid_t RDM_PID_DEVICE_POWER_CYCLES_CUSTOM = RDM_PID_DEVICE_POWER_CYCLES;
constexpr rdm_pid_t RDM_PID_MAX_POWER_PERCENT = 0x8001;

constexpr uint8_t PERSONALITY_MASTER_STROBE = 1;
constexpr uint8_t PERSONALITY_4CH_STROBE = 2;
constexpr uint8_t PERSONALITY_16BIT_STROBE = 3;

constexpr uint32_t STROBE_ON_TIME_US = 3000;
constexpr float STROBE_MIN_HZ = 1.0f;
constexpr float STROBE_MAX_HZ = 20.0f;
constexpr uint32_t DEBUG_PRINT_INTERVAL_MS = 500;
constexpr uint32_t SIGNAL_LOST_TIMEOUT_MS = 3000;
constexpr bool DEBUG_LOG_ENABLED = false;
constexpr uint8_t CPU_TEMP_SENSOR_NUM = 0;

const int dimmerPins[DIMMER_COUNT] = {DimmerPin0, DimmerPin1, DimmerPin2, DimmerPin3};
const int pwmChannels[DIMMER_COUNT] = {0, 1, 2, 3};

byte dmxValues[DMX_PACKET_SIZE] = {0};
uint16_t dimmerValues[DIMMER_COUNT] = {0};
volatile uint8_t strobeValue = 0;
uint16_t dmxStartAddress = DMX_START_ADDRESS;
uint8_t activePersonality = PERSONALITY_4CH_STROBE;

bool dmxConnected = false;
unsigned long lastDMXTime = 0;
unsigned long lastSignalTime = 0;
unsigned long lastDebugPrintMs = 0;
unsigned long rdmPacketCount = 0;
unsigned long dmxPacketCount = 0;
unsigned long lastSensorUpdateMs = 0;
uint32_t rdmDeviceHours = 0;
uint32_t rdmLampHours = 0;
uint32_t rdmDevicePowerCycles = 0;
uint8_t rdmMaxPowerPercent = 100;
bool rdmDevicePowerCyclesRegistered = false;
bool rdmMaxPowerRegistered = false;
uint32_t deviceMsAccumulator = 0;
uint32_t lampMsAccumulator = 0;
unsigned long lastHoursTickMs = 0;

bool strobeOn = true;
unsigned long lastToggleMicros = 0;

/**
 * @brief RDM callback for DEVICE_POWER_CYCLES access.
 * @details Ensures the parameter remains effectively read-only by restoring the
 * persisted runtime value whenever a SET is attempted.
 */
void rdmDevicePowerCyclesCallback(dmx_port_t dmxPort,
                                  rdm_header_t *request_header,
                                  rdm_header_t *response_header,
                                  void *context) {
  (void)dmxPort;
  (void)request_header;
  (void)response_header;
  (void)context;
}

/**
 * @brief RDM callback for Max Power % updates.
 * @details Clamps non-compliant values to 100 for runtime safety.
 */
void rdmMaxPowerCallback(dmx_port_t dmxPort, rdm_header_t *request_header,
                         rdm_header_t *response_header, void *context) {
  (void)dmxPort;
  (void)response_header;
  (void)context;

  if (request_header->cc != RDM_CC_SET_COMMAND) {
    return;
  }

  uint8_t value = rdmMaxPowerPercent;
  if (dmx_parameter_copy(DMX_PORT, RDM_SUB_DEVICE_ROOT, RDM_PID_MAX_POWER_PERCENT,
                         &value, sizeof(value)) == 0) {
    return;
  }

  if (value > 100) {
    value = 100;
  }
  rdmMaxPowerPercent = value;
}

/**
 * @brief Registers RDM DEVICE_POWER_CYCLES parameter.
 * @details Adds a persistent RDM parameter definition for power-cycle count.
 * @return True when parameter registration succeeded.
 */
bool registerDevicePowerCyclesParameter() {
  const rdm_pid_t pid = RDM_PID_DEVICE_POWER_CYCLES_CUSTOM;
  uint32_t initValue = 0;

  dmx_nvs_get(DMX_PORT, RDM_SUB_DEVICE_ROOT, pid, &initValue, sizeof(initValue));

  if (!dmx_parameter_add(DMX_PORT, RDM_SUB_DEVICE_ROOT, pid,
                         DMX_PARAMETER_TYPE_NON_VOLATILE, &initValue,
                         sizeof(initValue))) {
    return false;
  }

    static rdm_parameter_definition_t definition = {};
    static bool definitionInitialized = false;
    if (!definitionInitialized) {
      definition.pid_cc = RDM_CC_GET;
      definition.ds = RDM_DS_UNSIGNED_DWORD;
      definition.get.handler = rdm_simple_response_handler;
      definition.get.request.format = NULL;
      definition.get.response.format = "d$";
      definition.set.handler = NULL;
      definition.set.request.format = NULL;
      definition.set.response.format = NULL;
      definition.pdl_size = sizeof(uint32_t);
      definition.max_value = UINT32_MAX;
      definition.min_value = 0;
      definition.default_value = 0;
      definition.units = RDM_UNITS_NONE;
      definition.prefix = RDM_PREFIX_NONE;
      definition.description = "Power Cycles";
      definitionInitialized = true;
    }

  if (!rdm_definition_set(DMX_PORT, RDM_SUB_DEVICE_ROOT, pid, &definition)) {
    return false;
  }

  rdmDevicePowerCyclesRegistered = true;
  return true;
}

/**
 * @brief Registers manufacturer-specific Max Power percent parameter.
 * @details Adds persistent GET/SET parameter in range 0..100.
 * @return True when registration succeeded.
 */
bool registerMaxPowerParameter() {
  const rdm_pid_t pid = RDM_PID_MAX_POWER_PERCENT;
  uint8_t initValue = 100;

  dmx_nvs_get(DMX_PORT, RDM_SUB_DEVICE_ROOT, pid, &initValue, sizeof(initValue));
  if (initValue > 100) {
    initValue = 100;
  }

  if (!dmx_parameter_add(DMX_PORT, RDM_SUB_DEVICE_ROOT, pid,
                         DMX_PARAMETER_TYPE_NON_VOLATILE, &initValue,
                         sizeof(initValue))) {
    return false;
  }

  static rdm_parameter_definition_t definition = {};
  static bool definitionInitialized = false;
  if (!definitionInitialized) {
    definition.pid_cc = RDM_CC_GET_SET;
    definition.ds = RDM_DS_UNSIGNED_BYTE;
    definition.get.handler = rdm_simple_response_handler;
    definition.get.request.format = NULL;
    definition.get.response.format = "b$";
    definition.set.handler = rdm_simple_response_handler;
    definition.set.request.format = "b$";
    definition.set.response.format = NULL;
    definition.pdl_size = sizeof(uint8_t);
    definition.max_value = 100;
    definition.min_value = 0;
    definition.default_value = 100;
    definition.units = RDM_UNITS_NONE;
    definition.prefix = RDM_PREFIX_NONE;
    definition.description = "Max Power %";
    definitionInitialized = true;
  }

  if (!rdm_definition_set(DMX_PORT, RDM_SUB_DEVICE_ROOT, pid, &definition)) {
    return false;
  }

  if (!rdm_callback_set(DMX_PORT, RDM_SUB_DEVICE_ROOT, pid,
                        rdmMaxPowerCallback, NULL)) {
    return false;
  }

  rdmMaxPowerPercent = initValue;
  rdmMaxPowerRegistered = true;
  return true;
}
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

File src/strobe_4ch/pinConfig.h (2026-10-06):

#pragma once

#define DimmerPin0  22
#define DimmerPin1  25
#define DimmerPin2  26
#define DimmerPin3  27

#define Max485_TR   21

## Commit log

2026-01-17 Update README with DMX channel details
    Added detailed DMX channel information for the ESP32 Stepper DMX board.
2026-01-18 test dmx receive and led dimmer functionality
2026-10-06 random commit
    [schematics-B_Cu.gbr, schematics-B_Mask.gbr, schematics-B_Paste.gbr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]
2026-10-07 Added configuration for DMX channel offsets in led_dimmer and motor_dmx main.cpp via wifi and webpage
